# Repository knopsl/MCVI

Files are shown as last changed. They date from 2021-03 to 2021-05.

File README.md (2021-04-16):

# MCVI

This is a simple MIDI to CV synth module in Kosmo format. It provides pitch and velocity CV, gate, and trigger for Note On events as well as pitch bend and modulation CV for one MIDI channel, and 1- and 4- pulse per quarter note clock outputs.

This project is adapted from [https://github.com/elkayem/midi2cv](https://github.com/elkayem/midi2cv). 

It handles a range of 88 MIDI notes, corresponding to a standard piano keyboard, using a 12 bit DAC. CV output is 0 V (for MIDI note 21, A0) to +7.25 V (MIDI note 88, C8). Note selection in case of multple keys pressed is governed by a switch selecting lowest note, highest note, or most recent note priority.

Pitch bend CV range is 0 to +1.0 V (0.5 V when centered). Velocity and modulation CV range is 0 to +4 V. Gate, trigger, and clock outputs are +5 V; trigger and clock pulse width is 20 ms.

The module is built around an Arduino Nano. The sketch uses the standard MIDI and SPI libraries.

## Documentation
* [Build notes](Docs/build_notes.md) 
* [Schematic](Docs/MCVI.pdf)
* [BOM](Docs/MCVI_bom.pdf)

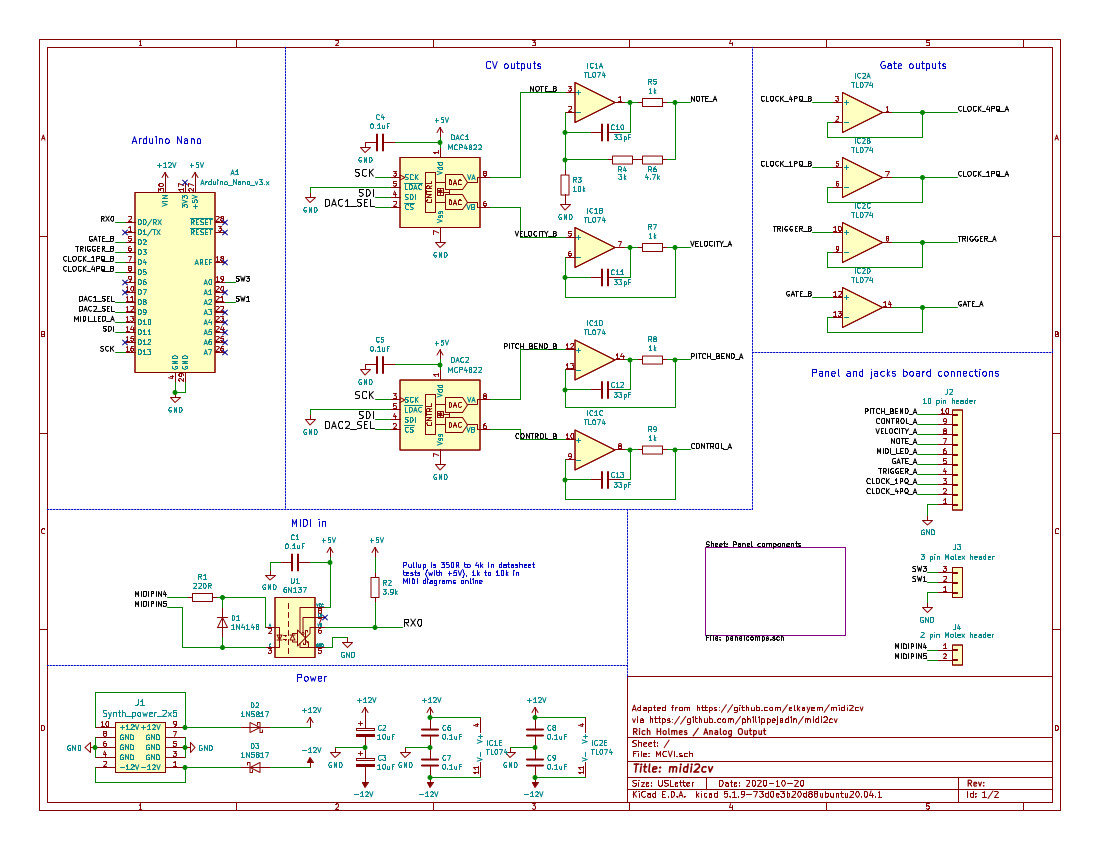
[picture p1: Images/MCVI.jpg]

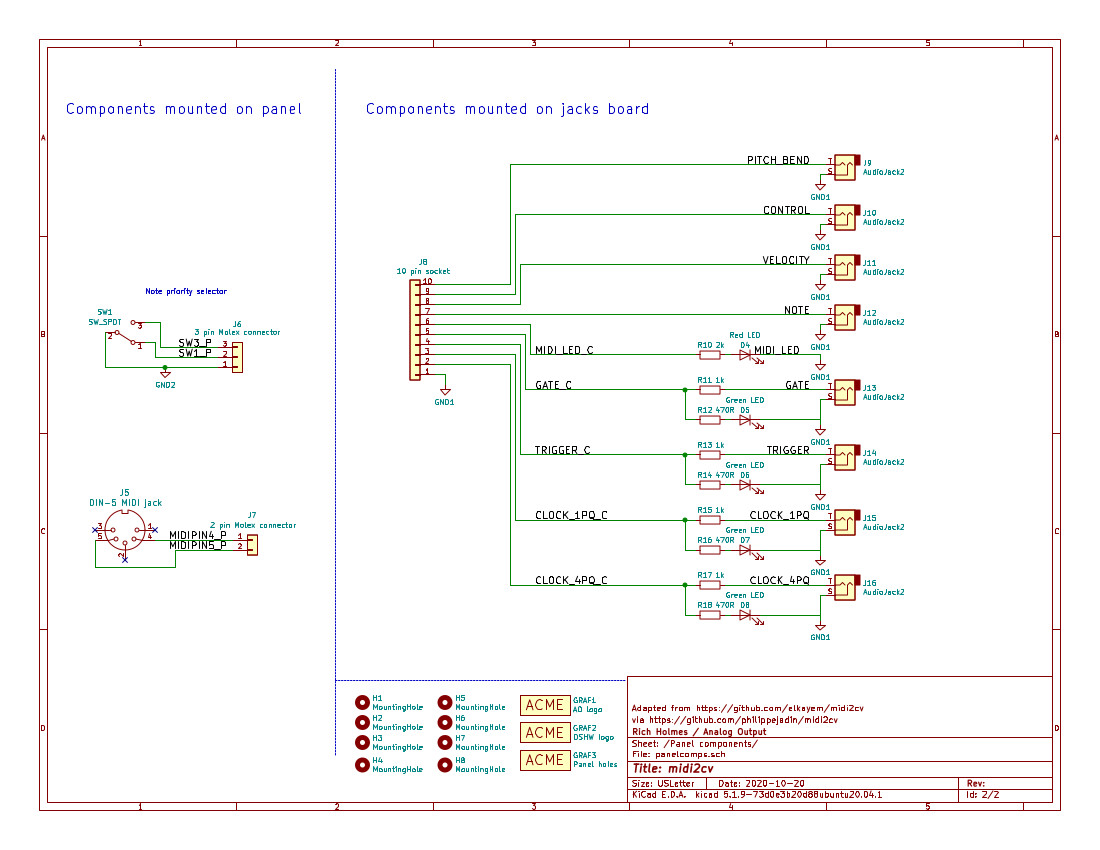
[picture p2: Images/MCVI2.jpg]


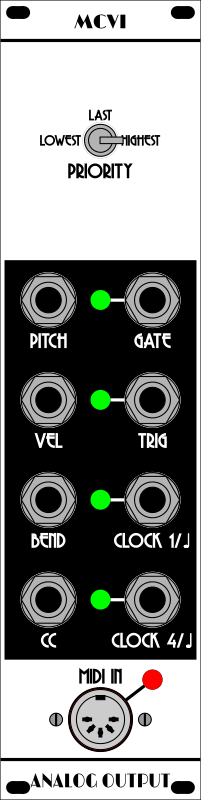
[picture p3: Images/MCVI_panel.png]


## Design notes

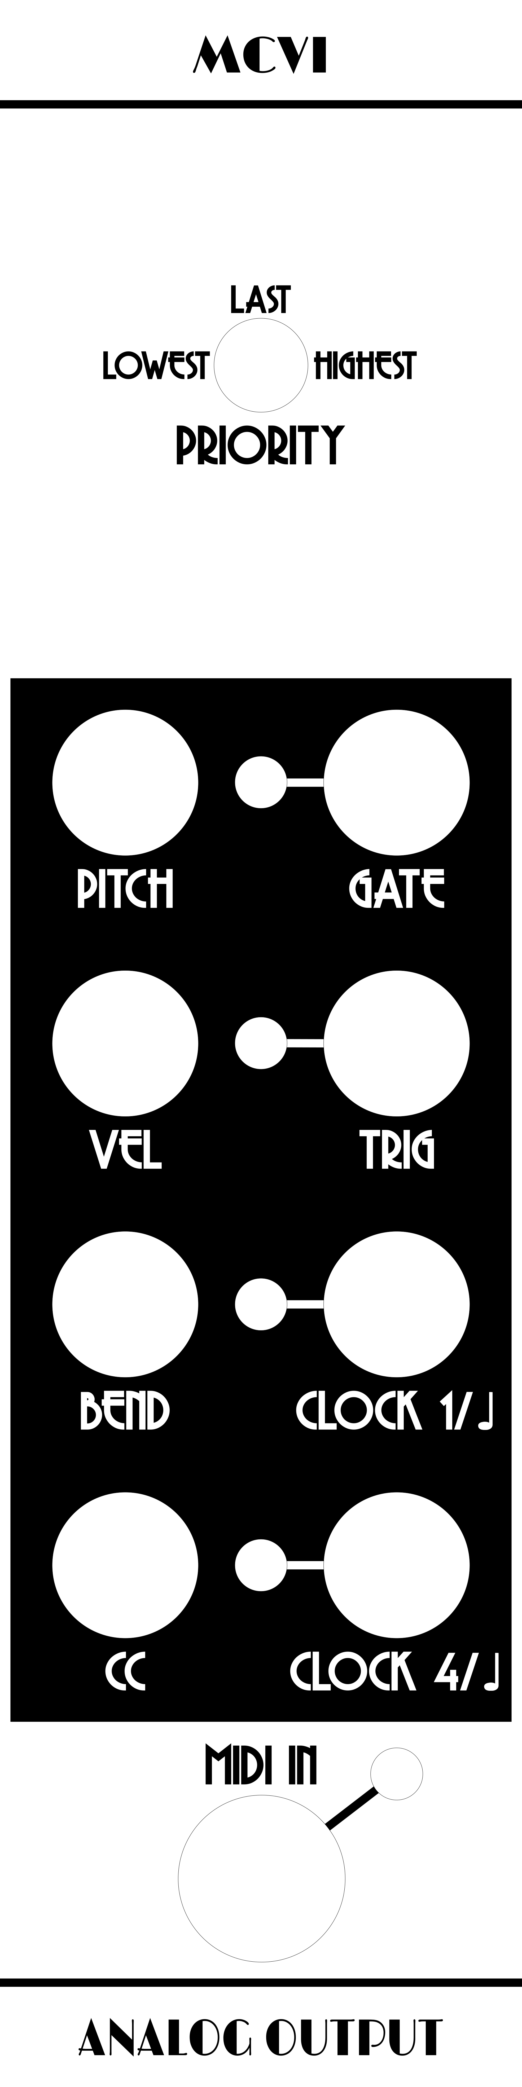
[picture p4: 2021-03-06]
Images/MCVI_panel_art.png

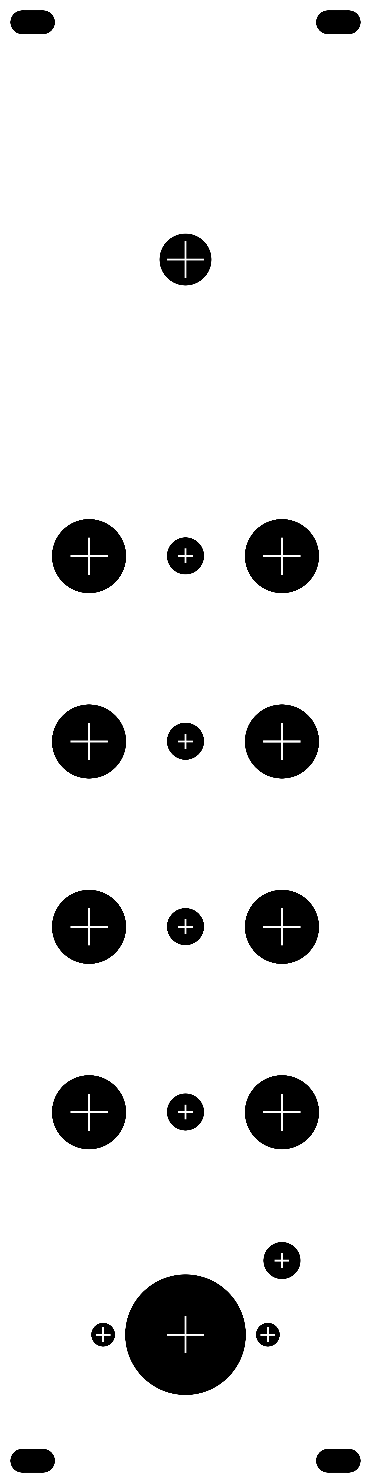
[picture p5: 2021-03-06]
Images/MCVI_panel_holes.png

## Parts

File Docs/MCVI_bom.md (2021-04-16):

# MCVI BOM

Thu 01 Apr 2021 07:22:17 PM EDT

Generated from schematic by Eeschema 5.1.9-73d0e3b20d~88~ubuntu20.04.1

**Component Count:** 62

| Refs | Qty | Component | Description | Vendor | SKU |
| ----- | --- | ---- | --- | ---- | ---- |
| A1 | 1 | Arduino_Nano_v3.x | Arduino Nano v3.x |  |  |
| C1, C4, C5, C6, C7, C8, C9 | 7 | 0.1uF | Ceramic capacitor |  |  |
| C2, C3 | 2 | 10uF | Electrolytic capacitor |  |  |
| C10, C11, C12, C13 | 4 | 33pF | Ceramic capacitor |  |  |
| D1 | 1 | 1N4148 | 100V 0.15A standard switching diode, DO-35 |  |  |
| D2, D3 | 2 | 1N5817 | Schottky diode |  |  |
| D4 | 1 | Red LED | Light emitting diode |  |  |
| D5, D6, D7, D8 | 4 | Green LED | Light emitting diode |  |  |
| DAC1, DAC2 | 2 | MCP4822 | 2-Channel 12-Bit D/A Converters with SPI Interface and Internal Reference (2.048V) |  |  |
| IC1, IC2 | 2 | TL074 | Quad Low-Noise JFET-Input Operational Amplifiers, DIP-14 |  |  |
| J1 | 1 | Synth_power_2x5 | 2x5 shrouded 2.54mm pin header |  |  |
| J2 | 1 | 10 pin header | Pin header, 2.54 mm spacing |  |  |
| J3 | 1 | 3 pin Molex header | 3 pin Molex header 2.54 mm spacing | Tayda | A-805 |
| J4 | 1 | 2 pin Molex header | 2 pin Molex header 2.54 mm spacing | Tayda | A-804 |
| J5 | 1 | DIN-5 MIDI jack | 5-pin DIN connector (5-pin DIN-5 stereo) |  |  |
| J6 | 1 | 3 pin Molex connector | 3 pin Molex connector 2.54 mm spacing | Tayda | A-827 |
| J7 | 1 | 2 pin Molex connector | 2 pin Molex connector 2.54 mm spacing | Tayda | A-826 |
| J8 | 1 | 10 pin socket | Pin socket, 2.54 mm spacing |  |  |
| J9, J10, J11, J12, J13, J14, J15, J16 | 8 | AudioJack2 | Audio Jack, 2 Poles (Mono / TS) |  |  |
| R1 | 1 | 220R | Resistor |  |  |
| R2 | 1 | 3.9k | Resistor |  |  |
| R3 | 1 | 10k | Resistor |  |  |
| R4 | 1 | 3k | Resistor |  |  |
| R5, R7, R8, R9, R11, R13, R15, R17 | 8 | 1k | Resistor |  |  |
| R6 | 1 | 4.7k | Resistor |  |  |
| R10 | 1 | 2k | Resistor |  |  |
| R12, R14, R16, R18 | 4 | 470R | Resistor |  |  |
| SW1 | 1 | SW_SPDT | Switch, single pole double throw |  |  |
| U1 | 1 | 6N137 | Optocoupler, DIP-8 |  |  |
| | 3 | | 8 pin DIP socket | | | | 
| | 2 | | 14 pin DIP socket | | | | 
| | 2 | | 15 pin header | | | |
| | 8 | | M3 6 mm screws | | | |
| | 8 | | M3 washers | | | |
| | 4 | | M3 10 mm spacers | | | |
   
Yes, there's IC1 and IC2 and DAC1 and DAC2 and U1. Sorry.

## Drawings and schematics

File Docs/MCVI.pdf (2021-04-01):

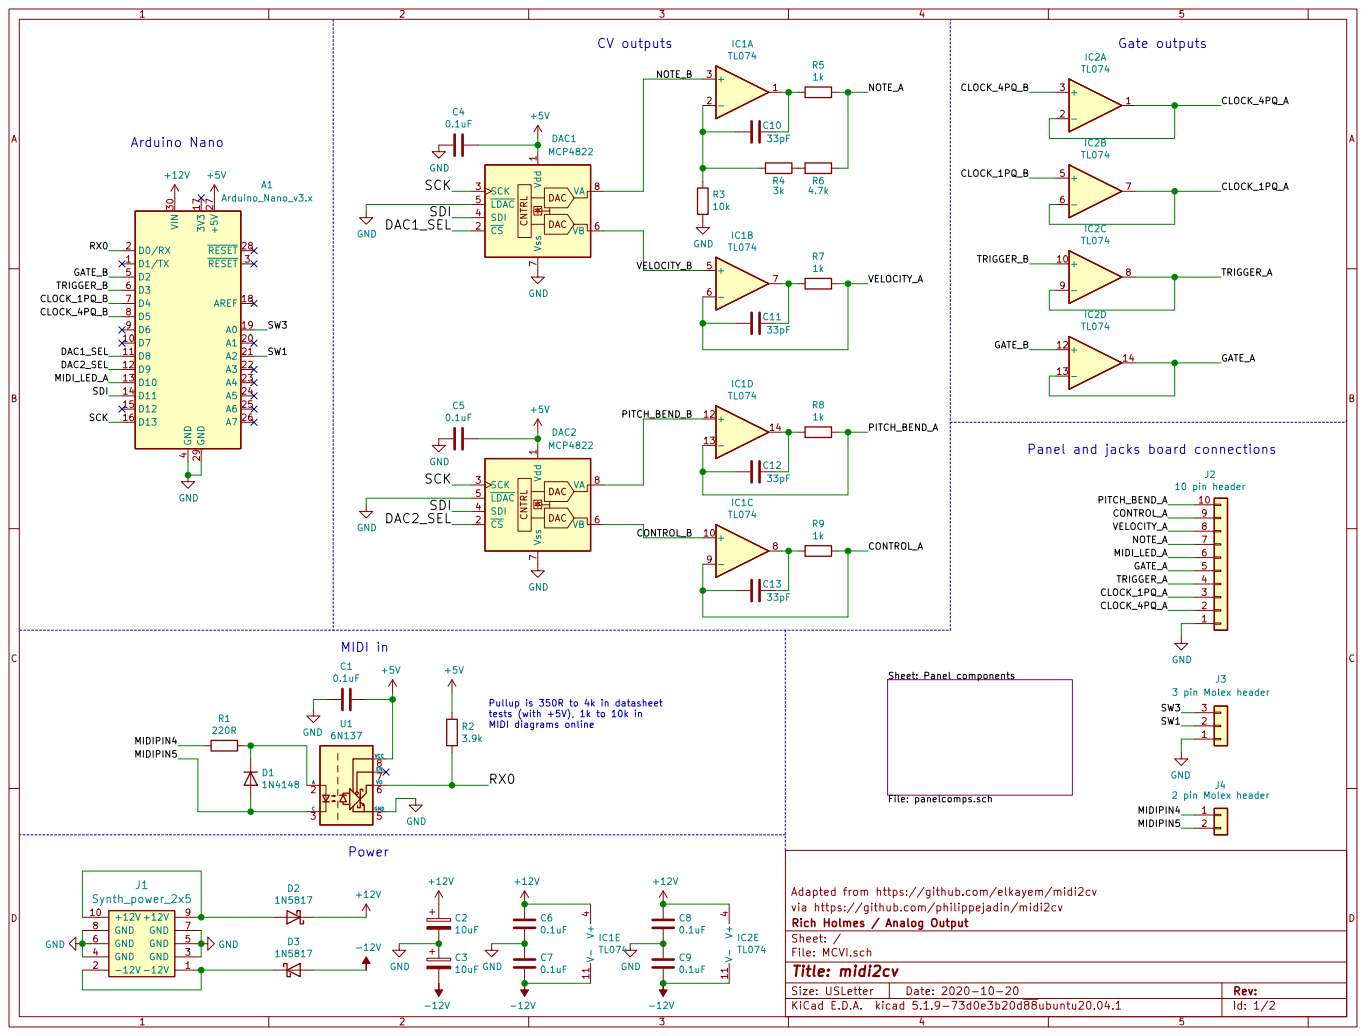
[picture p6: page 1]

Panel and jacks board connections

Pullup is 350R to 4k in datasheet
tests (with +5V), 1k to 10k in
MIDI diagrams online

Adapted from https://github.com/elkayem/midi2cv
via https://github.com/philippejadin/midi2cv
File: MCVI.sch Sheet: / Rich Holmes / Analog Output

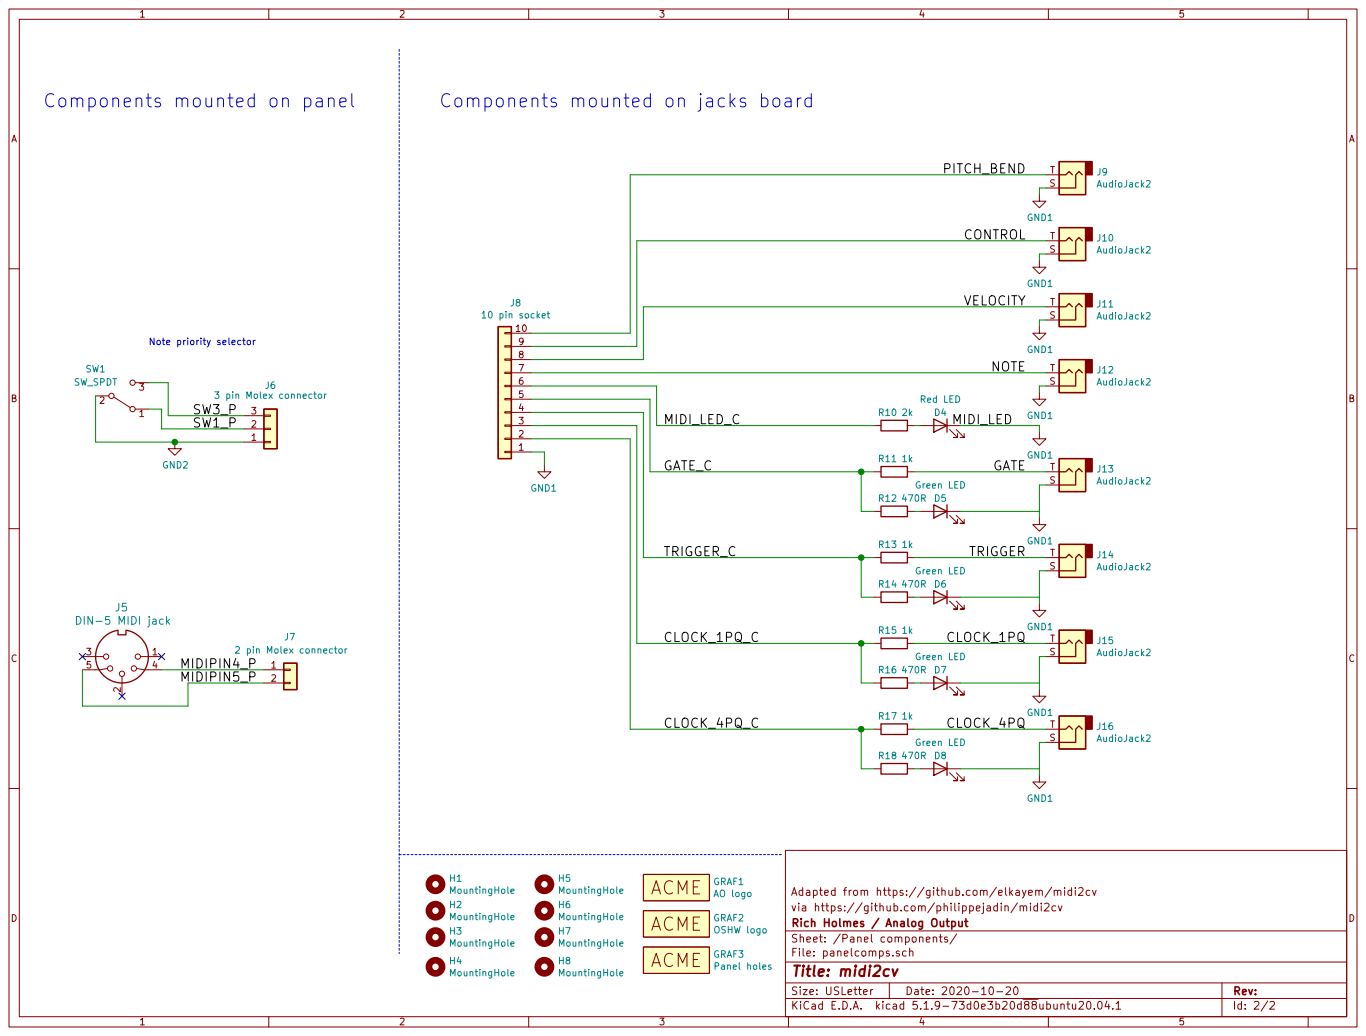
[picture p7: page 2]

via https://github.com/philippejadin/midi2cv
Rich Holmes / Analog Output
Sheet: /Panel components/
File: panelcomps.sch
Id: 2/2 Title: midi2cv

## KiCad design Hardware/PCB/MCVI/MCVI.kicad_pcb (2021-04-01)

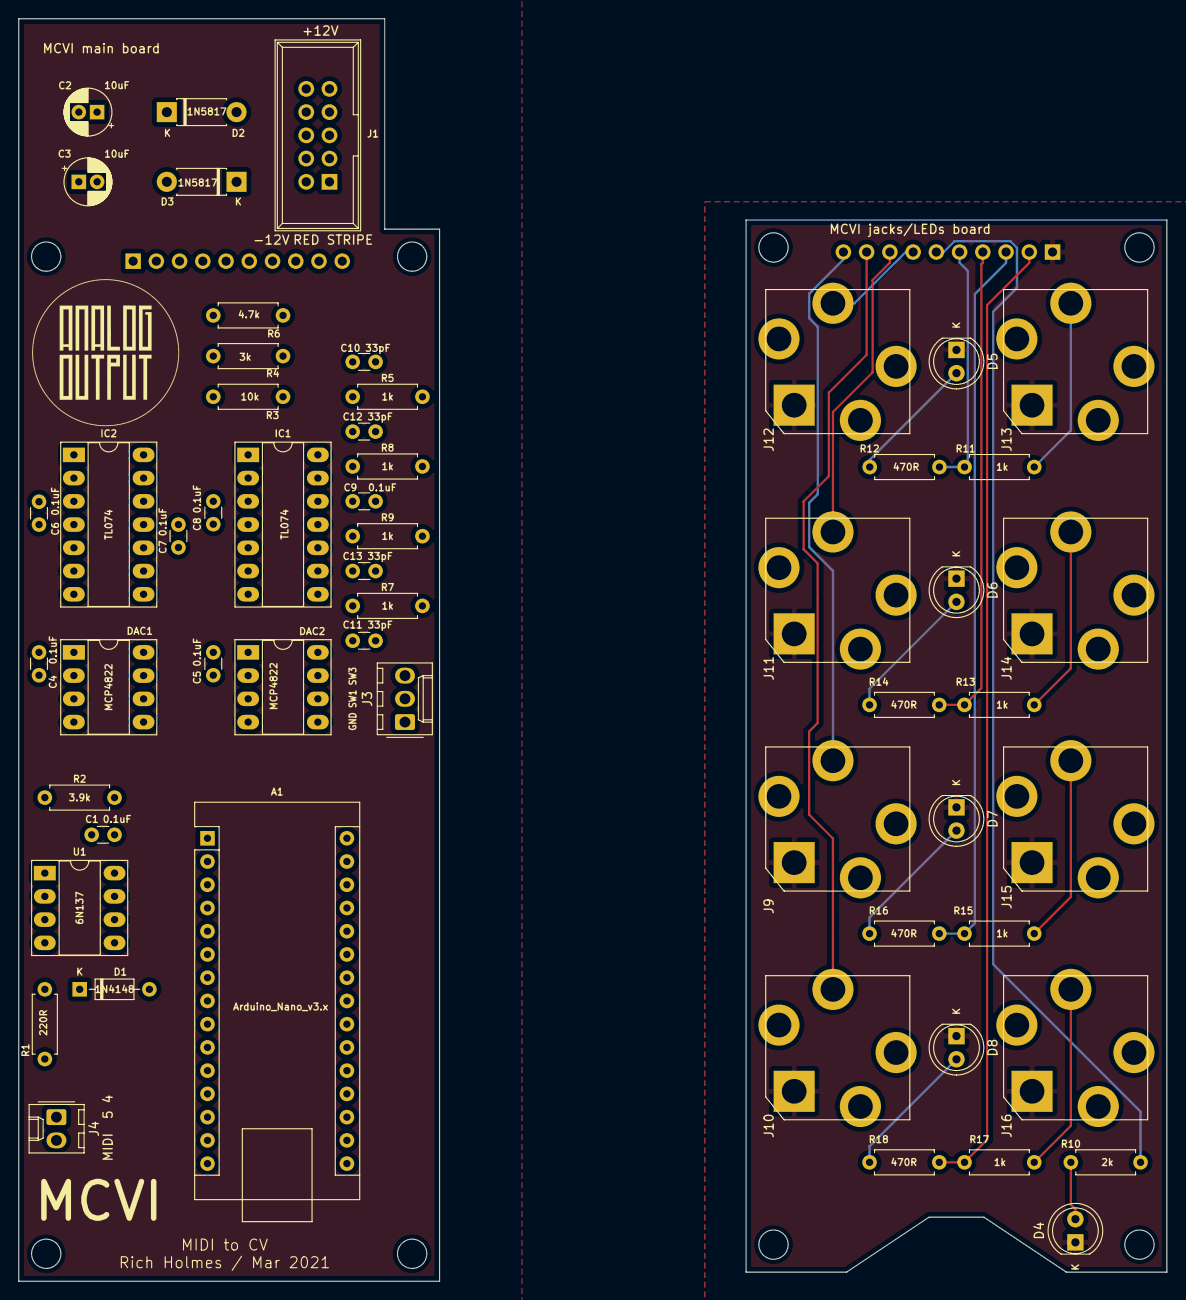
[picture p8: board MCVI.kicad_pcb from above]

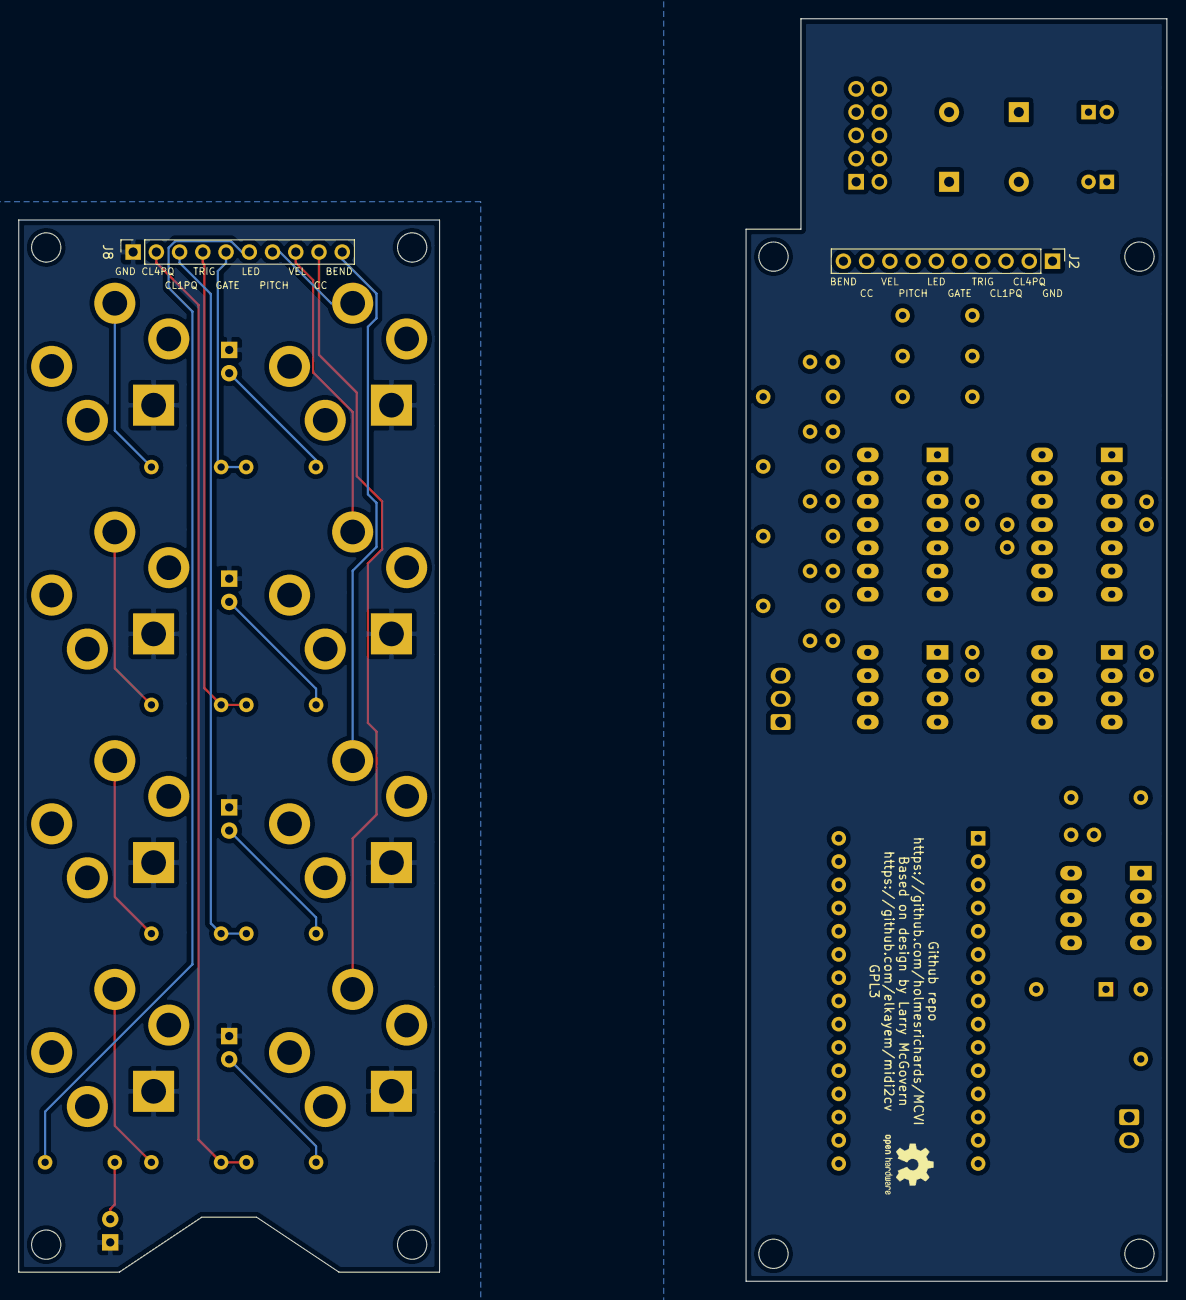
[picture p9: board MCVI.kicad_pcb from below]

Board: 2 copper layers, 125.5 x 138.0 mm, 69 parts (3 on the bottom side), 19 nets.

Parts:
A1: Arduino_Nano_v3.x; Arduino_Nano
C1, C4, C5, C6, C7, C8, C9: 0.1uF; C_Disc_D3.0mm_W1.6mm_P2.50mm
C2, C3: 10uF; CP_Radial_D5.0mm_P2.00mm
C10, C11, C12, C13: 33pF; C_Disc_D3.0mm_W1.6mm_P2.50mm
D1: 1N4148; D_DO-35_SOD27_P7.62mm_Horizontal
D2, D3: 1N5817; D_DO-41_SOD81_P7.62mm_Horizontal
D4: Red LED; LED_D5.0mm
D5, D6, D7, D8: Green LED; LED_D5.0mm
DAC1, DAC2: MCP4822; DIP-8_W7.62mm_Socket_LongPads
GRAF1: AO logo; analogoutput
GRAF2: OSHW logo; OSHW-Logo2_7.3x6mm_SilkScreen
GRAF3: Panel holes; MCVI_panel_holes
H1, H2, H3, H4, H5, H6, H7, H8: MountingHole; MountingHole_3.2mm_M3
IC1, IC2: TL074; DIP-14_W7.62mm_Socket_LongPads
J1: Synth_power_2x5; Power_Header
J2: 10 pin header; PinHeader_1x10_P2.54mm_Vertical
J3: 3 pin Molex header; Molex_KK-254_AE-6410-03A_1x03_P2.54mm_Vertical
J4: 2 pin Molex header; Molex_KK-254_AE-6410-02A_1x02_P2.54mm_Vertical
J8: 10 pin socket; PinSocket_1x10_P2.54mm_Vertical
J9, J10, J11, J12, J13, J14, J15, J16: AudioJack2; Jack_6.35mm_PJ_629HAN
R1: 220R; R_Axial_DIN0207_L6.3mm_D2.5mm_P7.62mm_Horizontal
R2: 3.9k; R_Axial_DIN0207_L6.3mm_D2.5mm_P7.62mm_Horizontal
R3: 10k; R_Axial_DIN0207_L6.3mm_D2.5mm_P7.62mm_Horizontal
R4: 3k; R_Axial_DIN0207_L6.3mm_D2.5mm_P7.62mm_Horizontal
R5, R7, R8, R9, R11, R13, R15, R17: 1k; R_Axial_DIN0207_L6.3mm_D2.5mm_P7.62mm_Horizontal
R6: 4.7k; R_Axial_DIN0207_L6.3mm_D2.5mm_P7.62mm_Horizontal
R10: 2k; R_Axial_DIN0207_L6.3mm_D2.5mm_P7.62mm_Horizontal
R12, R14, R16, R18: 470R; R_Axial_DIN0207_L6.3mm_D2.5mm_P7.62mm_Horizontal
U1: 6N137; DIP-8_W7.62mm_Socket_LongPads

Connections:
/Panel components/CLOCK_1PQ: J15.T, R15.1
/Panel components/CLOCK_1PQ_C: J8.3, R15.2, R16.2
/Panel components/CLOCK_4PQ: J16.T, R17.1
/Panel components/CLOCK_4PQ_C: J8.2, R17.2, R18.2
/Panel components/CONTROL: J8.9, J10.T
/Panel components/GATE: J13.T, R11.1
/Panel components/GATE_C: J8.5, R11.2, R12.2
/Panel components/MIDI_LED_C: J8.6, R10.2
/Panel components/NOTE: J8.7, J12.T
/Panel components/PITCH_BEND: J8.10, J9.T
/Panel components/TRIGGER: J14.T, R13.1
/Panel components/TRIGGER_C: J8.4, R13.2, R14.2
/Panel components/VELOCITY: J8.8, J11.T
GND1: D4.1, D5.1, D6.1, D7.1, D8.1, J8.1, J9.S, J10.S, J11.S, J12.S, J13.S, J14.S, J15.S, J16.S
unnamed: D4.2, R10.1
unnamed: D5.2, R12.1
unnamed: D6.2, R14.1
unnamed: D7.2, R16.1
unnamed: D8.2, R18.1

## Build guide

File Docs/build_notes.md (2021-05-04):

# MCVI Build Notes

This is a pretty straightforward build. I recommend socketing the Arduino Nano using two 15-position pin sockets. 

There are two PCBs, the main one and the jacks/LEDs board. They connect electrically via a 10-position pin header/socket pair and mechanically via M3 spacers and screws. 

As usual, place the jacks and LEDs on their board without soldering them, then mount the front panel, then solder the jacks and LEDs.

For the pin headers I used, the board separation is about 11 mm, so I used 10 mm spacers and a couple of washers. Connect the boards without soldering the pin header and socket, then solder them. See photo.

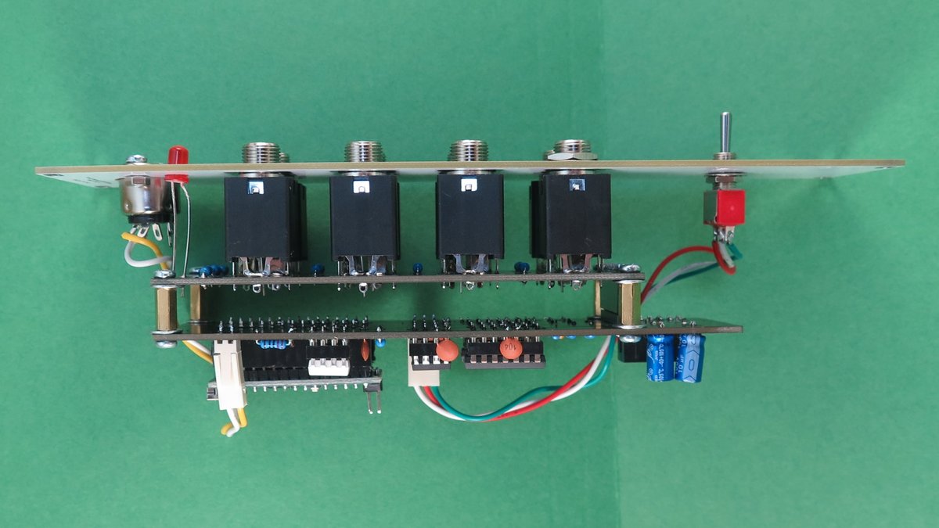
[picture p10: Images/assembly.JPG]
 

The MIDI jack and the switch are mounted to the front panel. You can solder their wires directly to the main PCB, or use Molex connectors/headers for easier disassembly when debugging. The notch at the top of the main circuit board can be used to help route the switch wires.

When looking at the panel from the back:

* The leftmost switch wire goes to the topmost hole (labeled SW3)
* The middle switch wire goes to the bottommost hole (labeled GND)
* The rightmost switch wire goes to the middle hole (labeled SW1)
* The pin immediately left of the bottom center pin on the MIDI jack connects to the topmost hole (labeled 4)
* The pin immediately right of the bottom center pin on the MIDI jack connects to the bottommost hole (labeled 5)
* The remaining MIDI jack pins are not connected.

See photos.

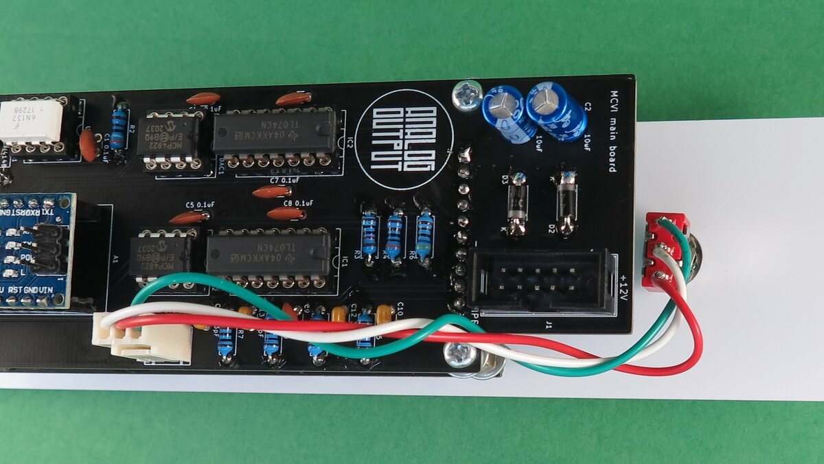
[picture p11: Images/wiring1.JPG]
 
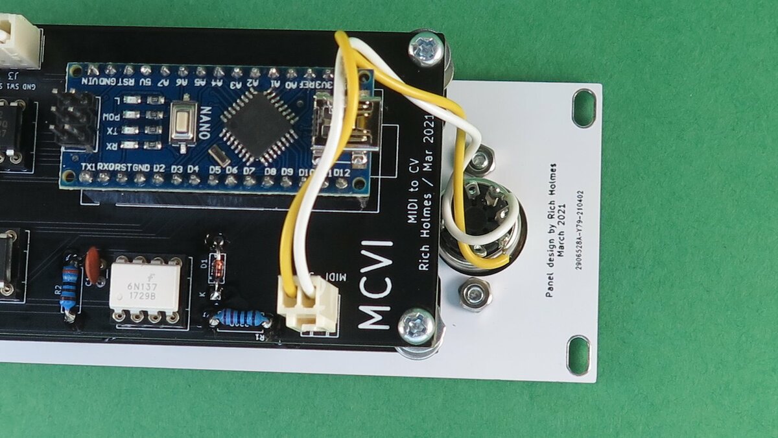
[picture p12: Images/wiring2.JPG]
 

*Mea culpa* for using a white wire for ground!

## Calibration

Connect a MIDI keyboard and measure voltages at the pitch CV output for different notes. A1 (lowest note on an 88 note keyboard) should produce 0 V — probably a few mV offset in reality — and each higher A should be 1.000 V higher, preferably within about 5 mV. C8 (last note on an 88 note keyboard) should produce 7.25 V. If you find each octave is systematically less than or more than 1.000 V there's a constant scale factor in the code (near the bottom) you can change to adjust the tuning. 

Even after such adjustment, DAC nonlinearity can result in inaccurate voltages at some level. I found I could get everything in the middle octaves within 5 cents (corresponding to 4 mV) of the correct value, with larger errors in the top and bottom octave or so. 

You might want to test several DAC chips and pick the one that performs best. The MCP4822 datasheet says the tolerance on the internal reference voltage is ±2%, and that will affect the scale factor. There also can be significant differences in linearity.

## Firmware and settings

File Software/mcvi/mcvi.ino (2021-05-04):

/*
  MIDI2CV
  Copyright (C) 2017  Larry McGovern

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
  This program is distributed in the hope that it will be useful,
  but WITHOUT ANY WARRANTY; without even the implied warranty of
  MERCHANTABILITY or FITNESS FOR A PARTICULAR PURPOSE.  See the
  GNU General Public License <http://www.gnu.org/licenses/> for more details.
*/

/*
  Version by Rich Holmes:
  * Some reformatting and reordering
  * Add 4 per quarter note clock
  * Listen only to selected channel
  * Ignore CC if not mod wheel

  License: GPL3 as above.
*/
#include <MIDI.h>
#include <SPI.h>

// Note priority is set by pins A0 and A2
// Highest note priority: A0 and A2 high (open)
// Lowest note priority:  A0 low (ground), A2 high (open)
// Last note priority:    A2 low (ground)

#define NP_SEL1 A0  // Note priority is set by pins A0 and A2
#define NP_SEL2 A2

#define GATE  2
#define TRIG  3
#define CLOCK_1PQ 4
#define CLOCK_4PQ 5
#define DAC1  8
#define DAC2  9
#define MIDILED 10

#define CHANNEL 1  // Use only this channel

MIDI_CREATE_DEFAULT_INSTANCE();

void setup()
{
  pinMode(NP_SEL1, INPUT_PULLUP);
  pinMode(NP_SEL2, INPUT_PULLUP);

  pinMode(GATE, OUTPUT);
  pinMode(TRIG, OUTPUT);
  pinMode(CLOCK_1PQ, OUTPUT);
  pinMode(CLOCK_4PQ, OUTPUT);
  pinMode(DAC1, OUTPUT);
  pinMode(DAC2, OUTPUT);
  pinMode(MIDILED, OUTPUT);
  digitalWrite(GATE, LOW);
  digitalWrite(TRIG, LOW);
  digitalWrite(CLOCK_1PQ, LOW);
  digitalWrite(CLOCK_4PQ, LOW);
  digitalWrite(DAC1, HIGH);
  digitalWrite(DAC2, HIGH);
  digitalWrite(MIDILED, LOW);

  SPI.begin();

  MIDI.begin(CHANNEL);

  // Set initial pitch bend voltage to 0.5V (mid point).  With Gain = 1X, this is 1023
  // Other DAC outputs will come up as 0V, so don't need to be initialized
  setVoltage(DAC2, 0, 0, 1023);
}

bool notes[88] = {0};
int8_t noteOrder[20] = {0}, orderIndx = {0};
unsigned long trigTimer = 0;

void loop()
{
  int type, noteMsg, velocity, d1, d2;
  static unsigned long clock_timer = 0, clock_timeout = 0;
  static unsigned int clock_count = 0;
  static unsigned long midiled_timer = 0;
  bool S1, S2;

  if ((midiled_timer > 0) && (millis() - midiled_timer > 20))
    {
      digitalWrite(MIDILED, LOW); // Set MIDI LED low after 20 msec
      midiled_timer = 0;
    }
    
  if ((trigTimer > 0) && (millis() - trigTimer > 20))
    {
      digitalWrite(TRIG, LOW); // Set trigger low after 20 msec
      trigTimer = 0;
    }

  if ((clock_timer > 0) && (millis() - clock_timer > 20))
    {
      digitalWrite(CLOCK_1PQ, LOW); // Set clock pulse low after 20 msec
      digitalWrite(CLOCK_4PQ, LOW); // Set clock pulse low after 20 msec
      clock_timer = 0;
    }

  if (MIDI.read())
    {
      digitalWrite(MIDILED, HIGH);
      midiled_timer = millis();
      byte type = MIDI.getType();
      switch (type)
	{
	case midi::ActiveSensing:
	  break;

	case midi::Clock:
	  if (millis() > clock_timeout + 300) clock_count = 0; // Prevents Clock from starting in between quarter notes after clock is restarted!
	  clock_timeout = millis();

	  // MIDI timing clock sends 24 pulses per quarter note.
	  // Sent CLOCK_1PQ pulse only once every 24 pulses
	  // Sent CLOCK_4PQ pulse only once every 6 pulses
	  
	  if (clock_count == 0)
	    digitalWrite(CLOCK_1PQ, HIGH); // Start CLOCK_1PQ pulse
	  if (clock_count == 0 || clock_count == 6
	      || clock_count == 12 || clock_count == 18)
	    {
	      digitalWrite(CLOCK_4PQ, HIGH); // Start CLOCK_4PQ pulse
	      clock_timer = millis();
	    }
	  clock_count++;
	  if (clock_count == 24)
	    clock_count = 0;
	  break;

	case midi::NoteOn:
	case midi::NoteOff:
	  noteMsg = MIDI.getData1() - 21; // A0 = 21, Top Note = 108
	  if ((noteMsg < 0) || (noteMsg > 87)) 
	    break; // Only 88 notes of keyboard are supported

	  if (type == midi::NoteOn) 
	    velocity = MIDI.getData2();
	  else 
	    velocity  = 0;

	  if (velocity == 0)
	    notes[noteMsg] = false;
	  else
	    {
	      notes[noteMsg] = true;
	      // velocity range from 0 to 4095 mV. Left shift d2 by 5
	      // to scale from 0 to 4095, and choose gain = 2X
	      setVoltage(DAC1, 1, 1, velocity << 5); // DAC1, channel 1, gain = 2X
	    }

	  // Pins NP_SEL1 and NP_SEL2 indictate note priority
	  S1 = digitalRead(NP_SEL1);
	  S2 = digitalRead(NP_SEL2);
	  if (S1 && !S2)
	    commandTopNote(); // Highest note priority
	  else if (!S1 && S2)
	    commandBottomNote(); // Lowest note priority
	  else
	    {
	      // Last note priority
	      if (notes[noteMsg])
		{
		  // If note is on and using last note priority, add
		  // to ordered list
		  orderIndx = (orderIndx + 1) % 20;
		  noteOrder[orderIndx] = noteMsg;
		}
	      commandLastNote();
	    }
	  break;

	case midi::PitchBend:
	  // Pitch bend output from 0 to 1023 mV.  Left shift d2 by 4
	  // to scale from 0 to 2047.  With DAC gain = 1X, this will
	  // yield a range from 0 to 1023 mV.
	  d2 = MIDI.getData2(); // d2 from 0 to 127, mid point = 64
	  setVoltage(DAC2, 0, 0, d2 << 4); // DAC2, channel 0, gain = 1X
	  break;

	case midi::ControlChange:
	  d1 = MIDI.getData1();
	  if (d1 != 1) // CC 1 (mod wheel) only
	    break;
	  
	  // CC range from 0 to 4095 mV Left shift d2 by 5 to scale
	  // from 0 to 4095, and choose gain = 2X
	  d2 = MIDI.getData2(); // From 0 to 127
	  setVoltage(DAC2, 1, 1, d2 << 5); // DAC2, channel 1, gain = 2X
	  break;

	default:
	  break;
	}
    }
}

void commandTopNote()
{
  int topNote = 0;
  bool noteActive = false;

  for (int i = 0; i < 88; i++)
    {
      if (notes[i])
	{
	  topNote = i;
	  noteActive = true;
	}
    }

  if (noteActive)
    commandNote(topNote);
  else // All notes are off, turn off gate
    digitalWrite(GATE, LOW);
}

void commandBottomNote()
{
  int bottomNote = 0;
  bool noteActive = false;

  for (int i = 87; i >= 0; i--)
    {
      if (notes[i])
	{
	  bottomNote = i;
	  noteActive = true;
	}
    }

  if (noteActive)
    commandNote(bottomNote);
  else // All notes are off, turn off gate
    digitalWrite(GATE, LOW);
}

void commandLastNote()
{

  int8_t noteIndx;

  for (int i = 0; i < 20; i++)
    {
      noteIndx = noteOrder[mod(orderIndx - i, 20)];
      if (notes[noteIndx])
	{
	  commandNote(noteIndx);
	  return;
	}
    }
  digitalWrite(GATE, LOW); // All notes are off
}

// Rescale 88 notes to 4096 mV:
//    noteMsg = 0 -> 0 mV
//    noteMsg = 87 -> 4096 mV

// DAC output will be (4095/87) = 47.069 mV per note, and 564.9655 mV
// per octave. Note that DAC output will need to be amplified by 1.77X
// for the standard 1V/octave.

#define NOTE_SF 47.069f // This value can be tuned if CV output isn't exactly 1V/octave

void commandNote(int noteMsg)
{
  digitalWrite(GATE, HIGH);
  digitalWrite(TRIG, HIGH);
  trigTimer = millis();

  unsigned int mV = (unsigned int) ((float) noteMsg * NOTE_SF + 0.5);
  setVoltage(DAC1, 0, 1, mV);  // DAC1, channel 0, gain = 2X
}

// setVoltage -- Set DAC voltage output

// dacpin: chip select pin for DAC.  Note and velocity on DAC1, pitch
// bend and CC on DAC2
//
// channel: 0 (A) or 1 (B).  Note and pitch bend on 0, velocity and CC on 2.
//
// gain: 0 = 1X, 1 = 2X.
//
// mV: integer 0 to 4095.  If gain is 1X, mV is in units of half mV
// (i.e., 0 to 2048 mV).
//
// If gain is 2X, mV is in units of mV.

void setVoltage(int dacpin, bool channel, bool gain, unsigned int mV)
{
  unsigned int command = channel ? 0x9000 : 0x1000;

  if (mV > 4095)
    mV = 4095;
  
  command |= gain ? 0x0000 : 0x2000;
  command |= mV;

  SPI.beginTransaction(SPISettings(8000000, MSBFIRST, SPI_MODE0));
  digitalWrite(dacpin, LOW);
  SPI.transfer(command >> 8);
  SPI.transfer(command & 0xFF);
  digitalWrite(dacpin, HIGH);
  SPI.endTransaction();
}

int mod(int a, int b)
{
  int r = a % b;
  return r < 0 ? r + b : r;
}

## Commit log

2020-10-29 Initial version
    [midi2cv_ao.kicad_pcb, midi2cv_ao.sch, panelcomps.sch]
2020-10-29 Add Teensy symbol/footprint; change output gain stages
    [midi2cv_ao.sch]
2020-10-30 Revert some changes (save for a later version)
    [midi2cv_ao.kicad_pcb, midi2cv_ao.sch, panelcomps.sch]
2020-11-21 General updates
    [midi2cv_ao-B_Cu.gbr, midi2cv_ao-B_Mask.gbr, midi2cv_ao-B_Paste.gbr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]
2021-01-02 Add buffers to digital outputs; change optoisolator
    [midi2cv_ao.kicad_pcb, midi2cv_ao.sch, panelcomps.sch]
2021-01-02 Jumper for hard/soft serial select
    [midi2cv_ao.kicad_pcb, midi2cv_ao.sch]
2021-01-17 Include lib table files; backlogged changes
    [midi2cv_ao.kicad_pcb, midi2cv_ao.sch, panelcomps.sch]
2021-01-23 Notes on voltage range offsets
2021-02-19 Footprints updated
2021-02-19 New routing
    [midi2cv_ao.kicad_pcb]
2021-02-25 Changed optoisolator, new layout
    [midi2cv_ao.kicad_pcb, midi2cv_ao.sch, panelcomps.sch]
2021-02-28 Rename project
    [MCVI.kicad_pcb, MCVI.sch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]
2021-03-04 Readme updates, button and bicolor LED will probably be omitted
    [MCVI.sch, panelcomps.sch]
2021-03-05 Add 4pq clock, ignore non channel 1, ignore CC other than mod wheel
2021-03-05 Some text revisions
    [MCVI.sch]
2021-03-06 Added in-loop series resistors and feedback capacitors on gate outputs.
    [MCVI.sch]
2021-03-06 Add MIDI LED to sketch
2021-03-06 Get rid of button and bicolor LED; reduce LED resistor values; SW1 to A2; cleanup
    [MCVI.sch, panelcomps.sch]
2021-03-06 Schematics cleanup
    [MCVI.sch, panelcomps.sch]
2021-03-06 New PCB layout
    [MCVI-B_Cu.gbr, MCVI-B_Mask.gbr, MCVI-B_Paste.gbr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]
2021-03-06 New PCB Gerbers; panel design
    [MCVI-B_Cu.gbr, MCVI-B_Mask.gbr, MCVI-B_Paste.gbr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]
2021-03-07 Schematics tweaks, BOM
    [MCVI-B_Cu.gbr, MCVI-B_Mask.gbr, MCVI-B_Paste.gbr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]
2021-04-01 Final revisions before fabrication
    [MCVI-B_Cu.gbr, MCVI-B_Mask.gbr, MCVI-B_Paste.gbr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]
2021-04-01 Gerbers, docs updates
    [MCVI-B_Cu.gbr, MCVI-B_Mask.gbr, MCVI-B_Paste.gbr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]
2021-04-10 BOM updates
2021-05-04 Calibration notes

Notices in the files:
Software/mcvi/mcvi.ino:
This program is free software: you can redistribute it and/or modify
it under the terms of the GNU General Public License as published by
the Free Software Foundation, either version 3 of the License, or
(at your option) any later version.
